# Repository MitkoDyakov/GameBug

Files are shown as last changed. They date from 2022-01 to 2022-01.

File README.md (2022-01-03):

# GameBug
Open Hardware gaming pads for breadboard. 

Each pad features:
* 1 x analog X Y joystics from Adafruit
* 4 x 1.96N OMRON push buttons
* 1 shoulder button
* RGB LED for backlight
* Haptic feedback Maxim Integrated PWM controled vibrator motor driver + motor
* All buttons are debounced using a Texas Instruments schmitt trigger IC to eliminate glitches. 
* 2 x selector switches from Alpine 

It has 2.54 pitch headers for dropping directly into a breadboard. It is powered by 5V or 3.3V.

Great for teaching childer about electronics by bilding their own games.

Suitable for creating your own portable games or HID Joystic devices. 

Can be used to control CNC machines or for DIY RC projects.

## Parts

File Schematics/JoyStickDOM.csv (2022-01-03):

Source: | C:\Users\Dimitar\Documents\PCb Prj\JoySticks\JoyStick\JoyStick.sch
Date: | 1/3/2022 3:54:24 PM
Tool: | Eeschema (5.1.9)-1
Component Count: | 95
Ref | Value | Footprint | Datasheet | Manufacturer | Vendor
C1 | 100nF | Capacitor_SMD:C_0603_1608Metric | ~
C2 | 100nF | Capacitor_SMD:C_0603_1608Metric | ~
C3 | 100nF | Capacitor_SMD:C_0603_1608Metric | ~
C4 | 100nF | Capacitor_SMD:C_0603_1608Metric | ~
C5 | 100nF | Capacitor_SMD:C_0603_1608Metric | ~
C6 | 100nF | Capacitor_SMD:C_0603_1608Metric | ~
C7 | 100nF | Capacitor_SMD:C_0603_1608Metric | ~
C8 | 100nF | Capacitor_SMD:C_0603_1608Metric | ~
C9 | 100nF | Capacitor_SMD:C_0603_1608Metric | ~
C10 | 100nF | Capacitor_SMD:C_0603_1608Metric | ~
C11 | 100nF | Capacitor_SMD:C_0603_1608Metric | ~
C12 | 100nF | Capacitor_SMD:C_0603_1608Metric | ~
C13 | 100nF | Capacitor_SMD:C_0603_1608Metric | ~
C14 | 100nF | Capacitor_SMD:C_0603_1608Metric | ~
D1 | GREEN | LED_SMD:LED_0603_1608Metric | https://github.com/MitkoDyakov/GameBug/blob/main/Datasheets/150060VS75000-1714627.pdf
D2 | GREEN | LED_SMD:LED_0603_1608Metric | https://github.com/MitkoDyakov/GameBug/blob/main/Datasheets/150060VS75000-1714627.pdf
D3 | GREEN | LED_SMD:LED_0603_1608Metric | https://github.com/MitkoDyakov/GameBug/blob/main/Datasheets/150060VS75000-1714627.pdf
D4 | GREEN | LED_SMD:LED_0603_1608Metric | https://github.com/MitkoDyakov/GameBug/blob/main/Datasheets/150060VS75000-1714627.pdf
J1 | Conn_01x06 | Connector_PinHeader_2.54mm:PinHeader_1x06_P2.54mm_Vertical | ~
J2 | Conn_01x07 | Connector_PinHeader_2.54mm:PinHeader_1x07_P2.54mm_Vertical | ~
J3 | Conn_01x02 | Connector_PinHeader_2.54mm:PinHeader_1x02_P2.54mm_Vertical | ~
J4 | Conn_01x06 | Connector_PinHeader_2.54mm:PinHeader_1x06_P2.54mm_Vertical | ~
J5 | Conn_01x02 | Connector_PinHeader_2.54mm:PinHeader_1x02_P2.54mm_Vertical | ~
J6 | Conn_01x05 | Connector_PinHeader_2.54mm:PinHeader_1x05_P2.54mm_Vertical | ~
J7 | Conn_01x02 | Connector_PinHeader_2.54mm:PinHeader_1x02_P2.54mm_Vertical | ~
LED1 | rgb | JoyStick:AELPS1.32 | https://github.com/MitkoDyakov/GameBug/blob/main/Datasheets/KRTB%20AELPS1.32_EN.pdf
LED2 | rgb | JoyStick:AELPS1.32 | https://github.com/MitkoDyakov/GameBug/blob/main/Datasheets/KRTB%20AELPS1.32_EN.pdf
M1 | 306-114 | JoyStick:306-114_motor | https://github.com/MitkoDyakov/GameBug/blob/main/Datasheets/306-114-datasheet-002-d2.2-id5506.pdf
M2 | 306-114 | JoyStick:306-114_motor | https://github.com/MitkoDyakov/GameBug/blob/main/Datasheets/306-114-datasheet-002-d2.2-id5506.pdf
Q1 | PDTC123TU,115 | JoyStick:SOT65P210X110-3N | https://github.com/MitkoDyakov/GameBug/blob/main/Datasheets/PDTC123T_SER-1599447.pdf
Q2 | PDTC123TU,115 | JoyStick:SOT65P210X110-3N | https://github.com/MitkoDyakov/GameBug/blob/main/Datasheets/PDTC123T_SER-1599447.pdf
Q3 | PDTC123TU,115 | JoyStick:SOT65P210X110-3N | https://github.com/MitkoDyakov/GameBug/blob/main/Datasheets/PDTC123T_SER-1599447.pdf
Q4 | PDTC123TU,115 | JoyStick:SOT65P210X110-3N | https://github.com/MitkoDyakov/GameBug/blob/main/Datasheets/PDTC123T_SER-1599447.pdf
Q5 | PDTC123TU,115 | JoyStick:SOT65P210X110-3N | https://github.com/MitkoDyakov/GameBug/blob/main/Datasheets/PDTC123T_SER-1599447.pdf
Q6 | PDTC123TU,115 | JoyStick:SOT65P210X110-3N | https://github.com/MitkoDyakov/GameBug/blob/main/Datasheets/PDTC123T_SER-1599447.pdf
R1 | 100R | Resistor_SMD:R_0603_1608Metric | ~
R2 | 100R | Resistor_SMD:R_0603_1608Metric | ~
R3 | 100R | Resistor_SMD:R_0603_1608Metric | ~
R4 | 4.7K | Resistor_SMD:R_0603_1608Metric | ~
R5 | 1K | Resistor_SMD:R_0603_1608Metric | ~
R6 | 4.7K | Resistor_SMD:R_0603_1608Metric | ~
R7 | 330R | Resistor_SMD:R_0603_1608Metric | ~
R8 | 330R | Resistor_SMD:R_0603_1608Metric | ~
R9 | R_Small | Resistor_SMD:R_0603_1608Metric | ~
R10 | R_Small | Resistor_SMD:R_0603_1608Metric | ~
R11 | 4.7K | Resistor_SMD:R_0603_1608Metric | ~
R12 | 100R | Resistor_SMD:R_0603_1608Metric | ~
R13 | 100R | Resistor_SMD:R_0603_1608Metric | ~
R14 | 100R | Resistor_SMD:R_0603_1608Metric | ~
R15 | 1K | Resistor_SMD:R_0603_1608Metric | ~
R16 | 1K | Resistor_SMD:R_0603_1608Metric | ~
R17 | 1K | Resistor_SMD:R_0603_1608Metric | ~
R18 | 1K | Resistor_SMD:R_0603_1608Metric | ~
R19 | 1K | Resistor_SMD:R_0603_1608Metric | ~
R20 | 1K | Resistor_SMD:R_0603_1608Metric | ~
R21 | 4.7K | Resistor_SMD:R_0603_1608Metric | ~
R22 | 4.7K | Resistor_SMD:R_0603_1608Metric | ~
R23 | 1K | Resistor_SMD:R_0603_1608Metric | ~
R24 | 1K | Resistor_SMD:R_0603_1608Metric | ~
R25 | 1K | Resistor_SMD:R_0603_1608Metric | ~
R26 | 4.7K | Resistor_SMD:R_0603_1608Metric | ~
R27 | 330R | Resistor_SMD:R_0603_1608Metric | ~
R28 | R_Small | Resistor_SMD:R_0603_1608Metric | ~
R29 | R_Small | Resistor_SMD:R_0603_1608Metric | ~
R30 | 330R | Resistor_SMD:R_0603_1608Metric | ~
R31 | 4.7K | Resistor_SMD:R_0603_1608Metric | ~
R32 | 4.7K | Resistor_SMD:R_0603_1608Metric | ~
R33 | 4.7K | Resistor_SMD:R_0603_1608Metric | ~
R34 | 4.7K | Resistor_SMD:R_0603_1608Metric | ~
R35 | 4.7K | Resistor_SMD:R_0603_1608Metric | ~
R36 | 4.7K | Resistor_SMD:R_0603_1608Metric | ~
R37 | 4.7K | Resistor_SMD:R_0603_1608Metric | ~
R38 | 4.7K | Resistor_SMD:R_0603_1608Metric | ~
R39 | 4.7K | Resistor_SMD:R_0603_1608Metric | ~
R40 | 4.7K | Resistor_SMD:R_0603_1608Metric | ~
SW1 | SW_Push | JoyStick:1825968-2 | ~
SW2 | B3AL-1000P | JoyStick:b3al-1000p | https://github.com/MitkoDyakov/GameBug/blob/main/Datasheets/en-b3al-6968.pdf
SW3 | B3AL-1000P | JoyStick:b3al-1000p | https://github.com/MitkoDyakov/GameBug/blob/main/Datasheets/en-b3al-6968.pdf
SW4 | B3AL-1000P | JoyStick:b3al-1000p | https://github.com/MitkoDyakov/GameBug/blob/main/Datasheets/en-b3al-6968.pdf
SW5 | B3AL-1000P | JoyStick:b3al-1000p | https://github.com/MitkoDyakov/GameBug/blob/main/Datasheets/en-b3al-6968.pdf
SW6 | B3AL-1000P | JoyStick:b3al-1000p | https://github.com/MitkoDyakov/GameBug/blob/main/Datasheets/en-b3al-6968.pdf
SW7 | B3AL-1000P | JoyStick:b3al-1000p | https://github.com/MitkoDyakov/GameBug/blob/main/Datasheets/en-b3al-6968.pdf
SW8 | SW_Push | JoyStick:1825968-2 | ~
SW9 | B3AL-1000P | JoyStick:b3al-1000p | https://github.com/MitkoDyakov/GameBug/blob/main/Datasheets/en-b3al-6968.pdf
SW10 | B3AL-1000P | JoyStick:b3al-1000p | https://github.com/MitkoDyakov/GameBug/blob/main/Datasheets/en-b3al-6968.pdf
U1 | SN74HCS14PWR | JoyStick:SOP65P640X120-14N | https://github.com/MitkoDyakov/GameBug/blob/main/Datasheets/sn74hcs14.pdf
U2 | 485-2765 | JoyStick:JOYSTICK_ANALOG_MINITHM | https://github.com/MitkoDyakov/GameBug/blob/main/Datasheets/2765_Web.pdf
U3 | positionSwitch | JoyStick:CL-SB-22A-01 | https://github.com/MitkoDyakov/GameBug/blob/main/Datasheets/cl-sb.pdf
U4 | positionSwitch | JoyStick:CL-SB-22A-01 | https://github.com/MitkoDyakov/GameBug/blob/main/Datasheets/cl-sb.pdf
U5 | MAX1749EUK | JoyStick:21-0057F | https://github.com/MitkoDyakov/GameBug/blob/main/Datasheets/MAX1749-1515329.pdf
U6 | 485-2765 | JoyStick:JOYSTICK_ANALOG_MINITHM | https://github.com/MitkoDyakov/GameBug/blob/main/Datasheets/2765_Web.pdf
U7 | SN74HCS14PWR | JoyStick:SOP65P640X120-14N | https://github.com/MitkoDyakov/GameBug/blob/main/Datasheets/sn74hcs14.pdf
U8 | CL-SB-22A-01T | JoyStick:CL-SB-22A-01 | https://github.com/MitkoDyakov/GameBug/blob/main/Datasheets/cl-sb.pdf
U9 | MAX1749EUK | JoyStick:21-0057F | https://github.com/MitkoDyakov/GameBug/blob/main/Datasheets/MAX1749-1515329.pdf
U10 | CL-SB-22A-01T | JoyStick:CL-SB-22A-01 | https://github.com/MitkoDyakov/GameBug/blob/main/Datasheets/cl-sb.pdf

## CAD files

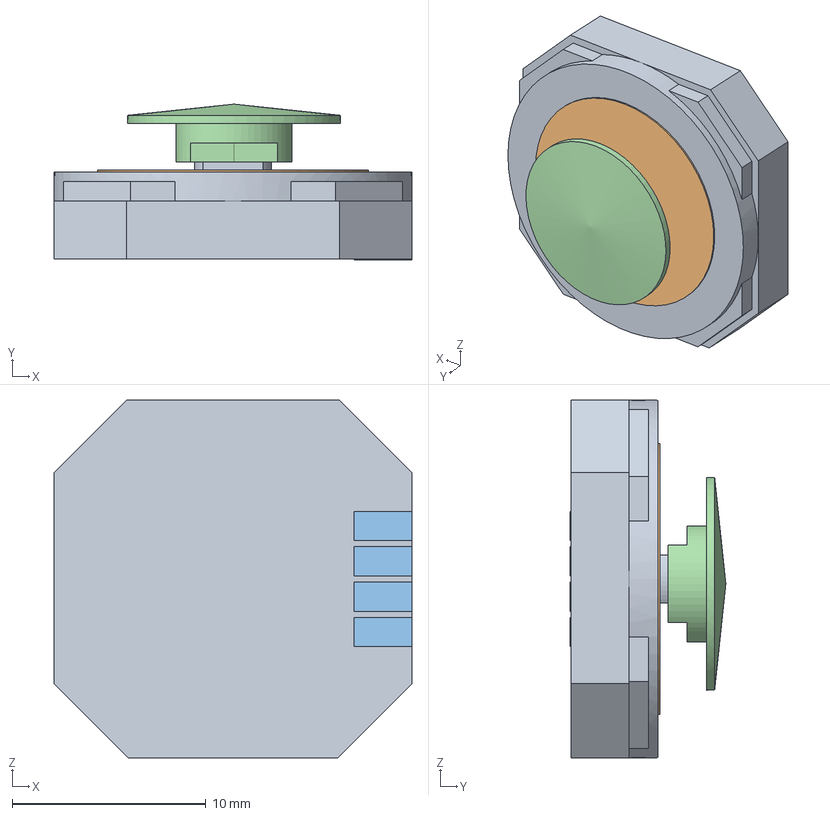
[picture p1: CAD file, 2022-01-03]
CAD models/components/joyStick.step
18.5 x 8.05 x 18.5 mm

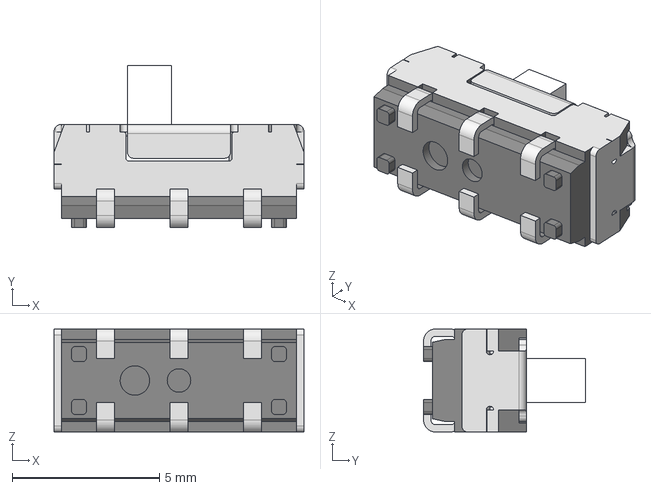
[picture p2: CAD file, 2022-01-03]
CAD models/components/CL-SB-22A-01.stp
8.50 x 5.50 x 3.50 mm
_22A-01_c
_2Top setting_s

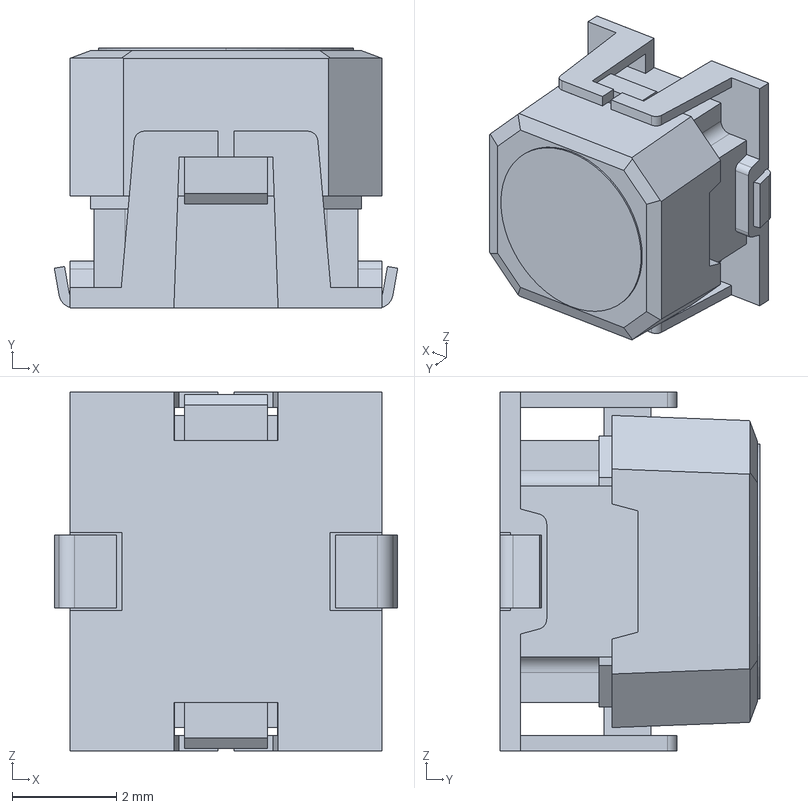
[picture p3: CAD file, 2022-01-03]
CAD models/components/omron_btn.stp
6.60 x 5.00 x 6.90 mm

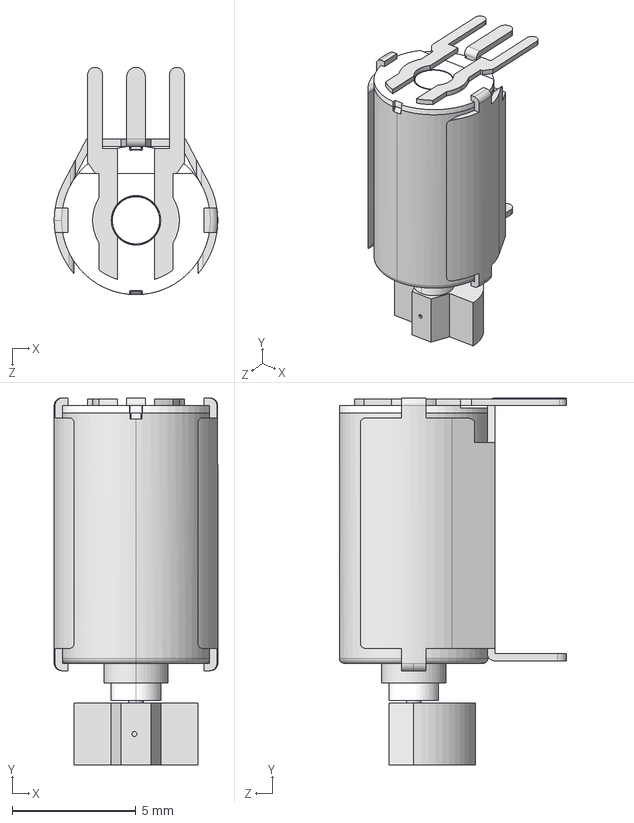
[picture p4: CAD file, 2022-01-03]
CAD models/components/motor.STEP
6.60 x 14.8 x 9.17 mm
m_main___
M_cover___
m_main cover___
weight___

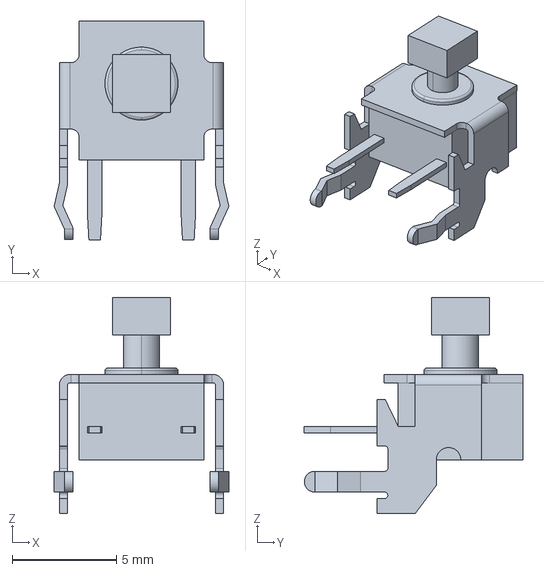
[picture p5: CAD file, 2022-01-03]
CAD models/components/c-1825968-2-b-3d.stp
8.40 x 10.5 x 10.4 mm

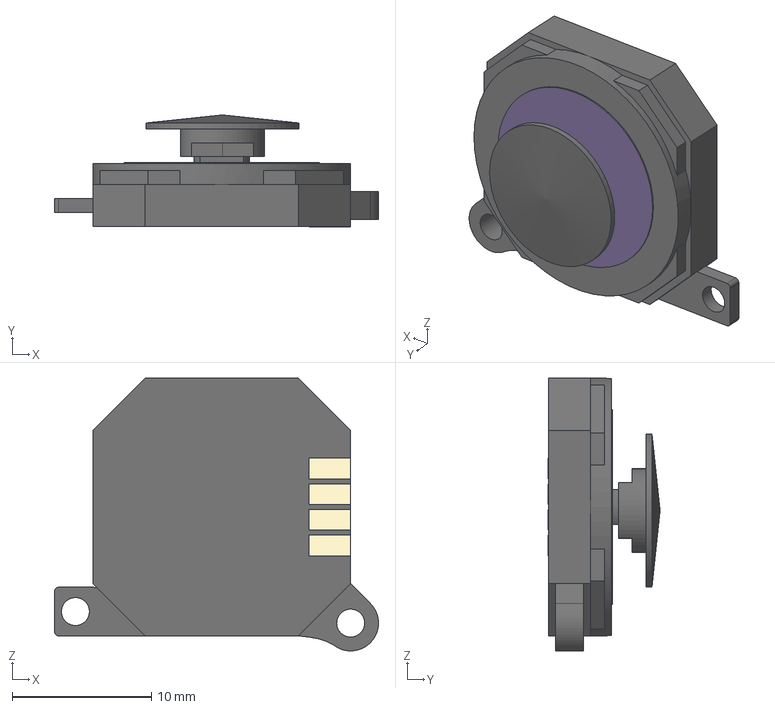
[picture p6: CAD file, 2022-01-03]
CAD models/components/PspJoystick v5.step
23.2 x 8.05 x 19.6 mm

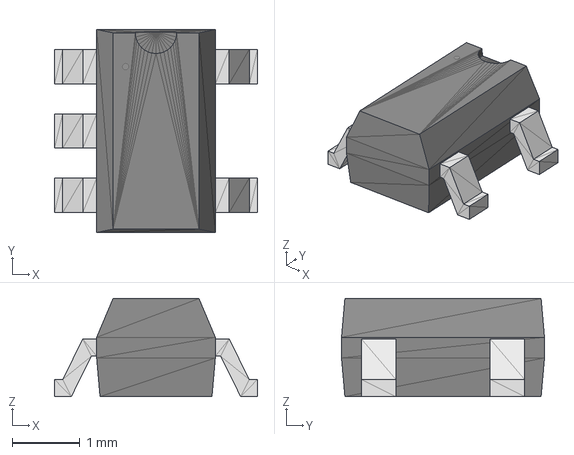
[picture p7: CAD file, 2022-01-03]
CAD models/components/MAX1749EUK+.STEP
3.00 x 3.00 x 1.45 mm

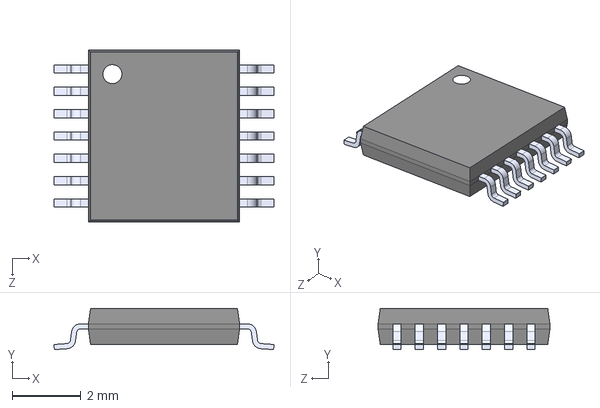
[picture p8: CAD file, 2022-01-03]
CAD models/components/SOP65P640X120-14N.step
6.40 x 1.20 x 5.00 mm

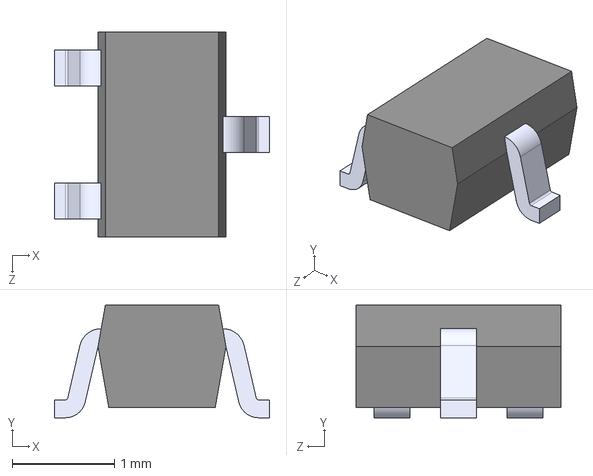
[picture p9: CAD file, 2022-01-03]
CAD models/components/SOT65P210X110-3N.step
2.10 x 1.10 x 2.00 mm

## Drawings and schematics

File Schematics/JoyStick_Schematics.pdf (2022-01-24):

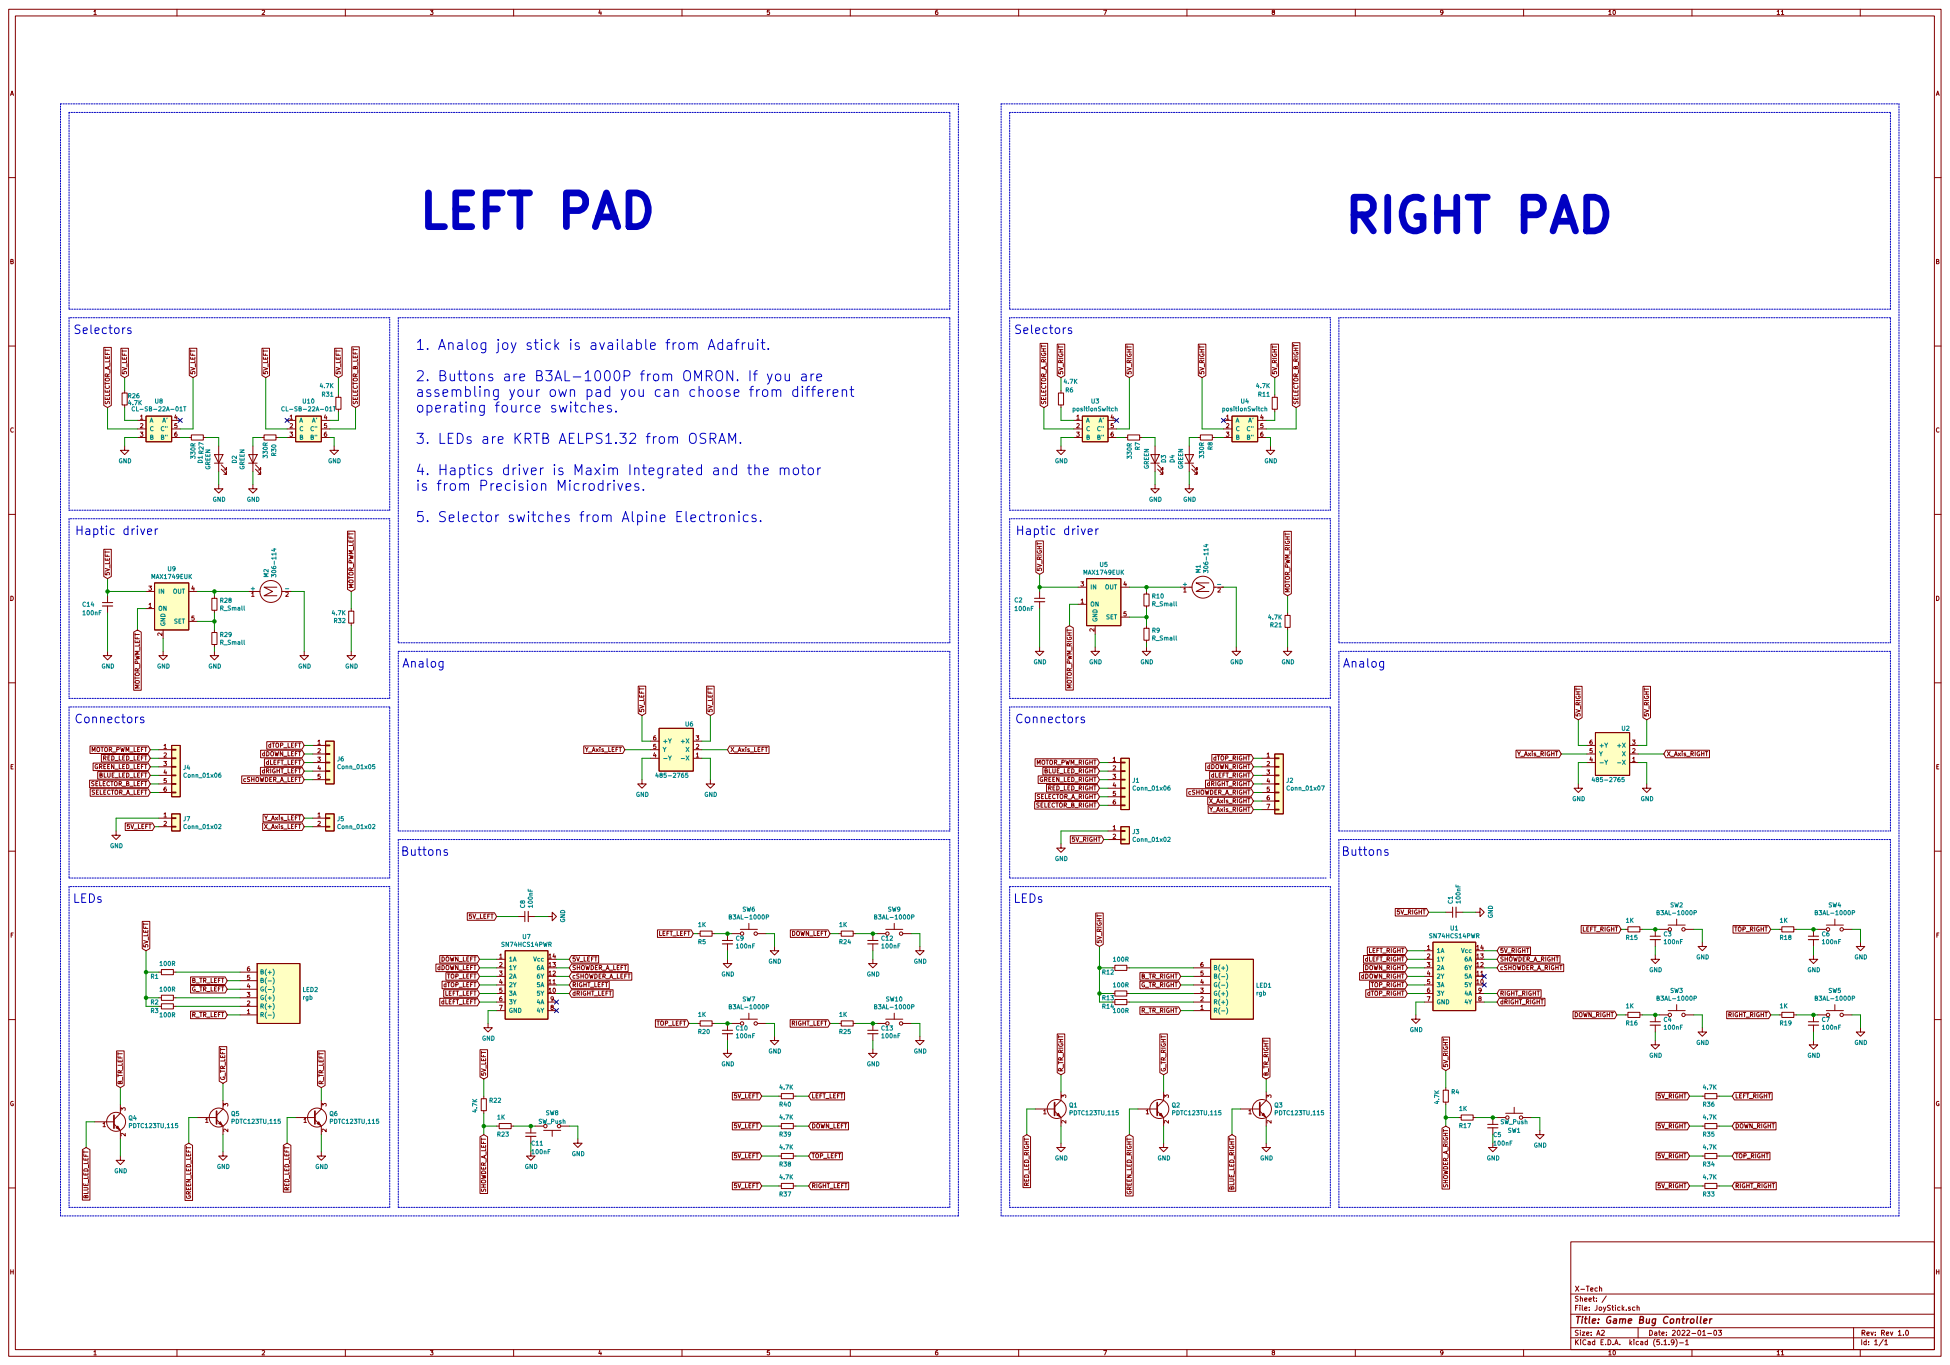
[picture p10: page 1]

1. Analog joy stick is available from Adafruit.
2. Buttons are B3AL-1000P from OMRON. If you are
assembling your own pad you can choose from different
operating fource switches.
3. LEDs are KRTB AELPS1.32 from OSRAM.
4. Haptics driver is Maxim Integrated and the motor
is from Precision Microdrives.
5. Selector switches from Alpine Electronics.

File: JoyStick.sch Sheet: / X-Tech 330R R30

Id: 1/1 Title: Game Bug Controller

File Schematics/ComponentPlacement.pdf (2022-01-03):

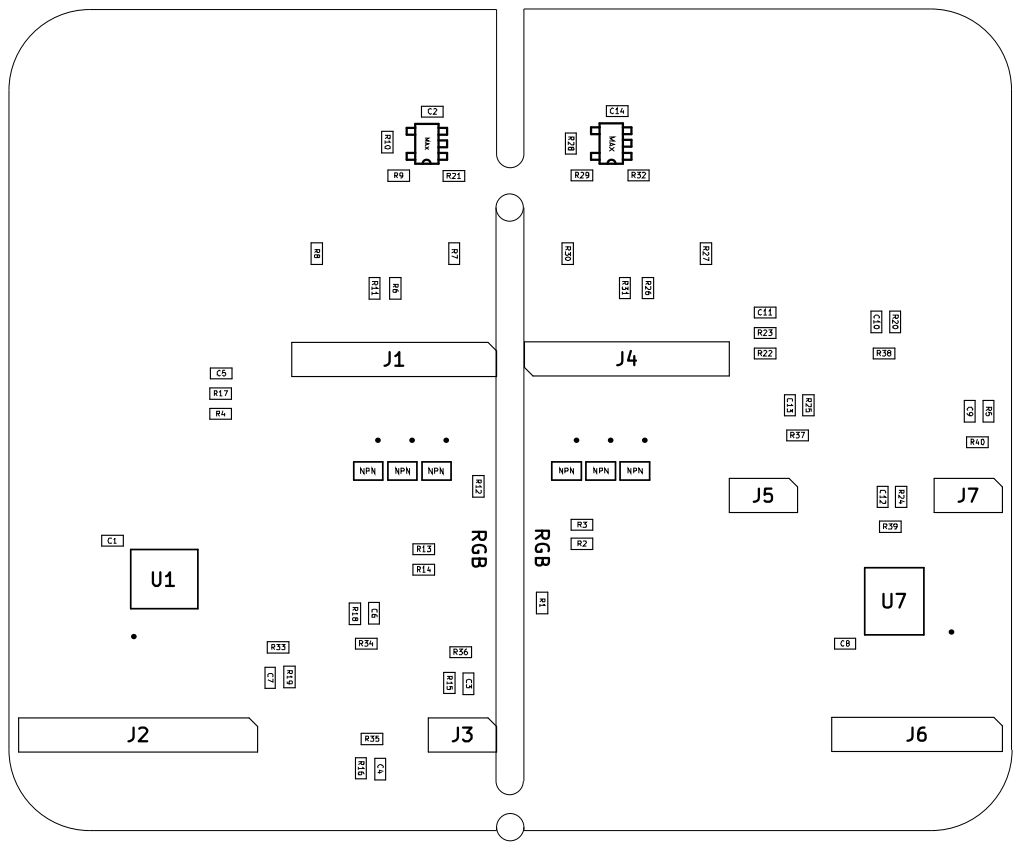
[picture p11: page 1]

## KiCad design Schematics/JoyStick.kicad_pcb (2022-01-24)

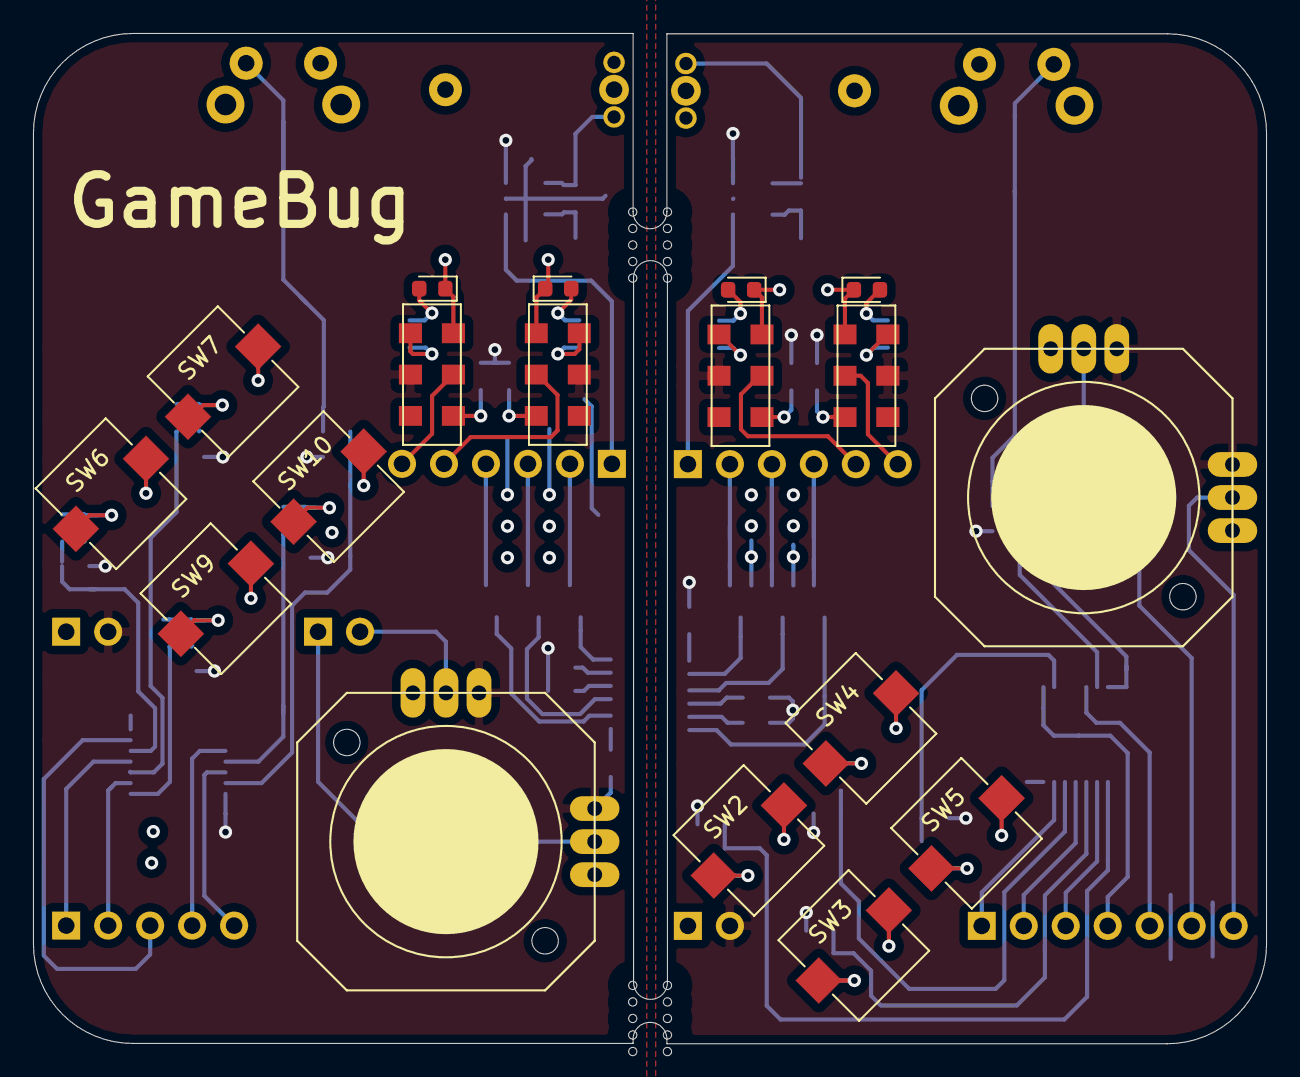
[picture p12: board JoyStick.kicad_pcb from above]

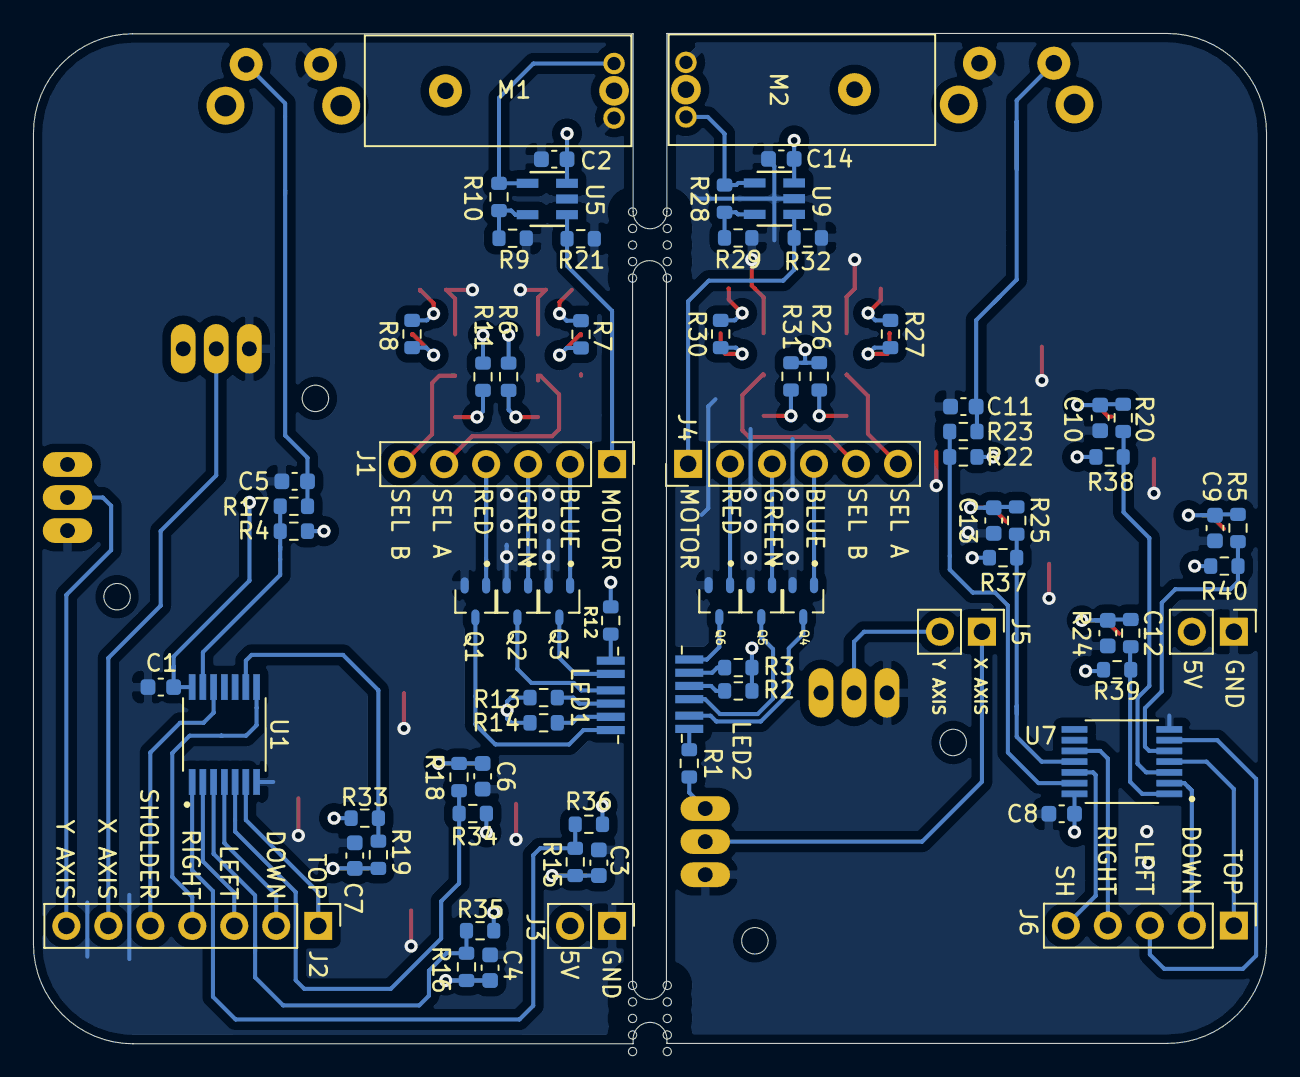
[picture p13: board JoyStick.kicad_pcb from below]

Board: 4 copper layers, 74.6 x 61.1 mm, 95 parts (75 on the bottom side), 77 nets.

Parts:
C1, C2, C3, C4, C5, C6, C7, C8, C9, C10, C11, C12, C13, C14: 100nF; C_0603_1608Metric
D1, D2, D3, D4: LED; LED_0603_1608Metric
J1, J4: Conn_01x06; PinHeader_1x06_P2.54mm_Vertical
J2: Conn_01x07; PinHeader_1x07_P2.54mm_Vertical
J3, J5, J7: Conn_01x02; PinHeader_1x02_P2.54mm_Vertical
J6: Conn_01x05; PinHeader_1x05_P2.54mm_Vertical
LED1, LED2: RGB; AELPS1.32
M1, M2: Motor_DC; 306-114_motor
Q1, Q2, Q3, Q4, Q5, Q6: NPN; SOT65P210X110-3N
R1, R2, R3, R4, R5, R6, R7, R8, R9, R10, R11, R12, R13, R14, R15, R16, R17, R18, R19, R20, R21, R22, R23, R24, R25, R26, R27, R28, R29, R30, R31, R32, R33, R34, R35, R36, R37, R38, R39, R40: R_Small; R_0603_1608Metric
SW1, SW8: SW_Push; 1825968-2
SW2, SW3, SW4, SW5, SW6, SW7, SW9, SW10: SW_Push; b3al-1000p
U1: U1; SOP65P640X120-14N
U2, U6: AnalogJoyStick; JOYSTICK_ANALOG_MINITHM
U3, U4, U8, U10: positionSwitch; CL-SB-22A-01
U5, U9: MAX; 21-0057F
U7: U7; SOP65P640X120-14N

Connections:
5V: C1.1, C2.1, J3.2, R4.2, R6.2, R11.2, R12.2, R13.2, R14.2, R33.1, R34.1, R35.1, R36.1, U1.14, U2.3, U2.6, U3.5, U4.2, U5.3
5V_2: C8.1, C14.1, J7.2, R1.2, R2.2, R3.2, R22.2, R26.2, R31.2, R37.1, R38.1, R39.1, R40.1, U6.3, U6.6, U7.14, U8.5, U9.3, U10.2
BLUE_LED: J1.2, Q3.1
BLUE_LED_2: J4.4, Q4.1
B_TR: LED1.5, Q3.3
B_TR_2: LED2.5, Q4.3
DOWN: R16.1, R35.2, U1.3
DOWN_2: R24.1, R39.2, U7.1
GND: C1.2, C2.2, C3.2, C4.2, C5.2, C6.2, C7.2, C8.2, C9.2, C10.2, C11.2, C12.2, C13.2, C14.2, D1.1, D2.1, D3.1, D4.1, J3.1, J7.1, M1.2, M2.2, Q1.2, Q2.2, Q3.2, Q4.2, Q5.2, Q6.2, R9.2, R21.1, R29.2, R32.1, SW1.2, SW2.2, SW3.2, SW4.2, SW5.2, SW6.2, SW7.2, SW8.1, SW9.2, SW10.2, U1.7, U2.1, U2.4, U3.3, U4.6, U5.2, U6.1, U6.4, U7.7, U8.3, U9.2, U10.6
GREEN_LED: J1.3, Q2.1
GREEN_LED_2: J4.3, Q5.1
G_TR: LED1.4, Q2.3
G_TR_2: LED2.4, Q5.3
LEFT: R15.1, R36.2, U1.1
LEFT_2: R5.1, R40.2, U7.5
MOTOR_PWM: J1.1, R21.2, U5.1
MOTOR_PWM_2: J4.1, R32.2, U9.1
unnamed: C3.1, R15.2, SW2.1
unnamed: C4.1, R16.2, SW3.1
unnamed: C5.1, R17.2, SW1.1
unnamed: C6.1, R18.2, SW4.1
unnamed: C7.1, R19.2, SW5.1
unnamed: C9.1, R5.2, SW6.1
unnamed: C10.1, R20.2, SW7.1
unnamed: C11.1, R23.2, SW8.2
unnamed: C12.1, R24.2, SW9.1
unnamed: C13.1, R25.2, SW10.1
unnamed: D1.2, R27.1
unnamed: D2.2, R30.2
unnamed: D3.2, R7.1
unnamed: D4.2, R8.2
unnamed: LED1.2, R14.1
unnamed: LED1.3, R13.1
unnamed: LED1.6, R12.1
unnamed: LED2.2, R3.1
unnamed: LED2.3, R2.1
unnamed: LED2.6, R1.1
unnamed: M1.1, R10.1, U5.4
unnamed: M2.1, R28.1, U9.4
unnamed: R6.1, U3.1
unnamed: R7.2, U3.6
unnamed: R8.1, U4.3
unnamed: R9.1, R10.2, U5.5
unnamed: R11.1, U4.4
unnamed: R26.1, U8.1
unnamed: R27.2, U8.6
unnamed: R28.2, R29.1, U9.5
unnamed: R30.1, U10.3
unnamed: R31.1, U10.4
RED_LED: J1.4, Q1.1
RED_LED_2: J4.2, Q6.1
RIGHT: R19.1, R33.2, U1.9
RIGHT_2: R25.1, R37.2, U7.11
R_TR: LED1.1, Q1.3
R_TR_2: LED2.1, Q6.3
SELECTOR_A: J1.5, U3.2
SELECTOR_A_2: J4.6, U8.2
SELECTOR_B: J1.6, U4.5
SELECTOR_B_2: J4.5, U10.5
SHOWDER_A: R4.1, R17.1, U1.13
SHOWDER_A_2: R22.1, R23.1, U7.13
TOP: R18.1, R34.2, U1.5
TOP_2: R20.1, R38.2, U7.3
X_Axis: J2.6, U2.2
X_Axis_2: J5.2, U6.2
Y_Axis: J2.7, U2.5
Y_Axis_2: J5.1, U6.5
cSHOWDER_A: J2.5, U1.12
cSHOWDER_A_2: J6.5, U7.12
dDOWN: J2.2, U1.4
dDOWN_2: J6.2, U7.2
dLEFT: J2.3, U1.2
dLEFT_2: J6.3, U7.6
dRIGHT: J2.4, U1.8
dRIGHT_2: J6.4, U7.10
dTOP: J2.1, U1.6
dTOP_2: J6.1, U7.4

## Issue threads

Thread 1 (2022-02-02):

Създадох този issue, защото не знаех как да се свържа с теб

NikolaTotev, 2022-02-02:
Здравей!
Знам че не е най-подходящия начин за комуникация, но само този канал намерих.
Твоя gamepad го видях на сайта на Hackster.io и се зарадвах като видях, че човека е българин!

Аз също си падам по електроника/роботика, и от дълго време търся други хора, които имат същите интереси.
Много бих се радвал ако може да си разменим някакви координати. За мен всичко работи, дискорд, фб, имейл и тн.

Поздрави,
Никола

MitkoDyakov, 2022-02-02:
Здравей Никола!

Разбира се ще се радвам да разменим контакти! Може да ми пратиш един мейл на dimitar ат xtech.bg

Поздрави,
Митко

Closed 2022-02-02.

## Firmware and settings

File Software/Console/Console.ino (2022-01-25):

#include <Arduino.h>
#include <XInput.h>

//LEFT PAD
#define LEFT_JOYSTICK_X_AXIS     (A3)
#define LEFT_JOYSTICK_Y_AXIS     (A2)

#define LEFT_VIBRATOR_MOTOR      (10)
#define LEFT_LIGHT_RED           (3)
#define LEFT_LIGHT_GREEN         (5)
#define LEFT_LIGHT_BLUE          (6)

//RIGHT PAD
#define RIGHT_JOYSTICK_X_AXIS    (A0)
#define RIGHT_JOYSTICK_Y_AXIS    (A1)
#define RIGHT_SHOULDER_BTN       (14)
#define RIGHT_BTN_UP             (9)
#define RIGHT_BTN_LEFT           (7)
#define RIGHT_BTN_RIGHT          (16)
#define RIGHT_BTN_DOWN           (8)

const int ADC_Max = 1023;  // 10 bit

void setup() 
{                
  pinMode(LEFT_JOYSTICK_X_AXIS, INPUT);
  pinMode(LEFT_JOYSTICK_Y_AXIS, INPUT);
  pinMode(LEFT_VIBRATOR_MOTOR, OUTPUT);
  pinMode(LEFT_LIGHT_RED, OUTPUT);
  pinMode(LEFT_LIGHT_GREEN, OUTPUT);
  pinMode(LEFT_LIGHT_BLUE, OUTPUT);

  pinMode(RIGHT_JOYSTICK_X_AXIS, INPUT);
  pinMode(RIGHT_JOYSTICK_Y_AXIS, INPUT);
  pinMode(RIGHT_SHOULDER_BTN, INPUT);
  pinMode(RIGHT_BTN_LEFT, INPUT);
  pinMode(RIGHT_BTN_RIGHT, INPUT);
  pinMode(RIGHT_BTN_DOWN, INPUT);

  XInput.setJoystickRange(0, ADC_Max);  // Set joystick range to the ADC
  XInput.setAutoSend(false);  // Wait for all controls before sending

  XInput.begin();
}

void loop() 
{
  boolean tmpVal = 0;
  int tmpJoyX = 0;
  int tmpJoyY = 0;
  
  tmpVal = digitalRead(RIGHT_BTN_DOWN);
  XInput.setButton(BUTTON_A, tmpVal);

  tmpVal = digitalRead(RIGHT_BTN_RIGHT);
  XInput.setButton(BUTTON_B, tmpVal);

  tmpVal = digitalRead(RIGHT_BTN_LEFT);
  XInput.setButton(BUTTON_X, tmpVal);
  
  tmpVal = digitalRead(RIGHT_BTN_UP);
  XInput.setButton(BUTTON_Y, tmpVal);

  tmpVal = digitalRead(RIGHT_SHOULDER_BTN);
  XInput.setButton(BUTTON_RB, tmpVal);
  
  tmpJoyX = analogRead(LEFT_JOYSTICK_X_AXIS);
  tmpJoyY = analogRead(LEFT_JOYSTICK_Y_AXIS);
  XInput.setJoystickX(JOY_LEFT, tmpJoyX, true);
  XInput.setJoystickY(JOY_LEFT, tmpJoyY, true);

  tmpJoyX = analogRead(RIGHT_JOYSTICK_X_AXIS);
  tmpJoyY = analogRead(RIGHT_JOYSTICK_Y_AXIS);
  XInput.setJoystickX(JOY_RIGHT, tmpJoyX, true);
  XInput.setJoystickY(JOY_RIGHT, tmpJoyY, true);

  // Send control data to the computer
  XInput.send();
}

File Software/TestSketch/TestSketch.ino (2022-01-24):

#include <Arduino.h>

// 1. Connect the GameBug pin to Arduino IO
// 2. Uncooment the control you are using
// 3. Write the pin number in the brackets 

//LEFT PAD INPUTS
//#define LEFT_JOYSTICK_X_AXIS     ()
//#define LEFT_JOYSTICK_Y_AXIS     ()
//#define LEFT_SHOULDER_BTN        ()
//#define LEFT_BTN_UP              ()
//#define LEFT_BTN_LEFT            ()
//#define LEFT_BTN_RIGHT           ()
//#define LEFT_BTN_DOWN            ()
//#define LEFT_SELECTOR_A          ()
//#define LEFT_SELECTOR_B          ()
//LEFT PAD OUTPUTS
//#define LEFT_VIBRATOR_MOTOR      ()
//#define LEFT_LIGHT_RED           ()
//#define LEFT_LIGHT_GREEN         ()
//#define LEFT_LIGHT_BLUE          ()

//RIGHT PAD INPUTS
//#define RIGHT_JOYSTICK_X_AXIS    ()
//#define RIGHT_JOYSTICK_Y_AXIS    ()
//#define RIGHT_SHOULDER_BTN       ()
//#define RIGHT_BTN_UP             ()
//#define RIGHT_BTN_LEFT           ()
//#define RIGHT_BTN_RIGHT          ()
//#define RIGHT_BTN_DOWN           ()
//#define RIGHT_SELECTOR_A         ()
//#define RIGHT_SELECTOR_B         ()
//RIGHT PAD OUTPUTS
//#define RIGHT_VIBRATOR_MOTOR     ()
//#define RIGHT_LIGHT_RED          ()
//#define RIGHT_LIGHT_GREEN        ()
//#define RIGHT_LIGHT_BLUE         ()

void setup() 
{
                 
#ifdef LEFT_JOYSTICK_X_AXIS   
  pinMode(LEFT_JOYSTICK_X_AXIS, INPUT);
#endif

#ifdef LEFT_JOYSTICK_Y_AXIS   
  pinMode(LEFT_JOYSTICK_Y_AXIS, INPUT);
#endif          
   
#ifdef LEFT_SHOULDER_BTN      
  pinMode(LEFT_SHOULDER_BTN, INPUT);
#endif

#ifdef LEFT_BTN_UP          
  pinMode(LEFT_BTN_UP, INPUT);
#endif
  
#ifdef LEFT_BTN_LEFT      
  pinMode(LEFT_BTN_LEFT, INPUT);
#endif
    
#ifdef LEFT_BTN_RIGHT     
  pinMode(LEFT_BTN_RIGHT, INPUT);
#endif
    
#ifdef LEFT_BTN_DOWN 
  pinMode(LEFT_BTN_DOWN, INPUT);
#endif
         
#ifdef LEFT_SELECTOR_A 
  pinMode(LEFT_SELECTOR_A, INPUT);
#endif
       
#ifdef LEFT_SELECTOR_B 
  pinMode(LEFT_SELECTOR_B, INPUT);
#endif
            
#ifdef LEFT_VIBRATOR_MOTOR    
  pinMode(LEFT_VIBRATOR_MOTOR, OUTPUT);
#endif

#ifdef LEFT_LIGHT_RED  
  pinMode(LEFT_LIGHT_RED, OUTPUT);
#endif
       
#ifdef LEFT_LIGHT_GREEN
  pinMode(LEFT_LIGHT_GREEN, OUTPUT);
#endif
       
#ifdef LEFT_LIGHT_BLUE   
  pinMode(LEFT_LIGHT_BLUE, OUTPUT);
#endif     
                  
#ifdef RIGHT_JOYSTICK_X_AXIS  
  pinMode(RIGHT_JOYSTICK_X_AXIS, INPUT);
#endif

#ifdef RIGHT_JOYSTICK_Y_AXIS  
  pinMode(RIGHT_JOYSTICK_Y_AXIS, INPUT);
#endif
                        
#ifdef RIGHT_SHOULDER_BTN   
  pinMode(RIGHT_SHOULDER_BTN, INPUT);
#endif
  
#ifdef RIGHT_BTN_UP 
  pinMode(RIGHT_BTN_UP, INPUT);
#endif
          
#ifdef RIGHT_BTN_LEFT   
  pinMode(RIGHT_BTN_LEFT, INPUT);
#endif
      
#ifdef RIGHT_BTN_RIGHT  
  pinMode(RIGHT_BTN_RIGHT, INPUT);
#endif
      
#ifdef RIGHT_BTN_DOWN 
  pinMode(RIGHT_BTN_DOWN, INPUT);
#endif
        
#ifdef RIGHT_SELECTOR_A   
  pinMode(RIGHT_SELECTOR_A, INPUT);
#endif
    
#ifdef RIGHT_SELECTOR_B   
  pinMode(RIGHT_SELECTOR_B, INPUT);
#endif    
                        
#ifdef RIGHT_VIBRATOR_MOTOR  
  pinMode(RIGHT_VIBRATOR_MOTOR, OUTPUT);
#endif
 
#ifdef RIGHT_LIGHT_RED    
  pinMode(RIGHT_LIGHT_RED, OUTPUT);
#endif
    
#ifdef RIGHT_LIGHT_GREEN 
  pinMode(RIGHT_LIGHT_GREEN, OUTPUT);
#endif
   
#ifdef RIGHT_LIGHT_BLUE  
  pinMode(RIGHT_LIGHT_BLUE, OUTPUT);
#endif

  Serial.begin(9600);
}

void loop() {
  int axis;
  uint8_t tmp = 0;

  Serial.println("\tLeft\t\tRight");
  Serial.print("X\t");
  
#ifdef LEFT_JOYSTICK_X_AXIS
  axis = analogRead(LEFT_JOYSTICK_X_AXIS);
  Serial.print(axis);
#else 
  Serial.print("NA");
#endif
  Serial.print("\t\t");
#ifdef RIGHT_JOYSTICK_X_AXIS
  axis = analogRead(RIGHT_JOYSTICK_X_AXIS);
  Serial.println(axis);
#else 
  Serial.println("NA");
#endif

Serial.print("Y\t");  
#ifdef LEFT_JOYSTICK_Y_AXIS
  axis = analogRead(LEFT_JOYSTICK_Y_AXIS);
  Serial.print(axis);
#else 
  Serial.print("NA");
#endif
  Serial.print("\t\t");
#ifdef RIGHT_JOYSTICK_Y_AXIS
  axis = analogRead(RIGHT_JOYSTICK_Y_AXIS);
  Serial.println(axis);
#else 
  Serial.println("NA");
#endif

  
  Serial.print("Sh\t");
#ifdef LEFT_SHOULDER_BTN
  tmp = digitalRead(LEFT_SHOULDER_BTN);
  Serial.print(tmp);
#else
  Serial.print("NA");
#endif
  Serial.print("\t\t");
#ifdef RIGHT_SHOULDER_BTN
  tmp = digitalRead(RIGHT_SHOULDER_BTN);
  Serial.println(tmp);
#else
  Serial.println("NA");
#endif
  
  Serial.print("L\t");
#ifdef LEFT_BTN_LEFT
  tmp = digitalRead(LEFT_BTN_LEFT);
  Serial.print(tmp);
#else
  Serial.print("NA");
#endif
  Serial.print("\t\t");
#ifdef RIGHT_BTN_LEFT
  tmp = digitalRead(RIGHT_BTN_LEFT);
  Serial.println(tmp);
#else
  Serial.println("NA");
#endif
  
  Serial.print("R\t");
#ifdef LEFT_BTN_RIGHT
  tmp = digitalRead(LEFT_BTN_RIGHT);
  Serial.print(tmp);
#else
  Serial.print("NA");
#endif
  Serial.print("\t\t");
#ifdef RIGHT_BTN_RIGHT
  tmp = digitalRead(RIGHT_BTN_RIGHT);
  Serial.println(tmp);
#else
  Serial.println("NA");
#endif
  
  Serial.print("U\t");
#ifdef LEFT_BTN_UP
  tmp = digitalRead(LEFT_BTN_UP);
  Serial.print(tmp);
#else
  Serial.print("NA");
#endif
  Serial.print("\t\t");
#ifdef RIGHT_BTN_UP
  tmp = digitalRead(RIGHT_BTN_UP);
  Serial.println(tmp);
#else
  Serial.println("NA");
#endif
  
  Serial.print("D\t");
#ifdef LEFT_BTN_DOWN
  tmp = digitalRead(LEFT_BTN_DOWN);
  Serial.print(tmp);
#else
  Serial.print("NA");
#endif
  Serial.print("\t\t");
#ifdef RIGHT_BTN_DOWN
  tmp = digitalRead(RIGHT_BTN_DOWN);
  Serial.println(tmp);
#else
  Serial.println("NA");
#endif
  
  Serial.print("SA\t");
#ifdef LEFT_SELECTOR_A
  tmp = digitalRead(LEFT_SELECTOR_A);
  Serial.print(tmp);
#else
  Serial.print("NA");
#endif
  Serial.print("\t\t");
#ifdef RIGHT_SELECTOR_A
  tmp = digitalRead(RIGHT_SELECTOR_A);
  Serial.println(tmp);
#else
  Serial.println("NA");
#endif
  
  Serial.print("SB\t");
#ifdef LEFT_SELECTOR_B
  tmp = digitalRead(LEFT_SELECTOR_B);
  Serial.print(tmp);
#else
  Serial.print("NA");
#endif
  Serial.print("\t\t");
#ifdef RIGHT_SELECTOR_B
  tmp = digitalRead(RIGHT_SELECTOR_B);
  Serial.println(tmp);
#else
  Serial.println("NA");
#endif

  Serial.println();
  Serial.println("send L for LED demo or M for motor demo");
  Serial.println("-----------------------------------------------------------------");
  Serial.println();


  uint8_t i = 0;
  int incomingByte = 0;

  if (Serial.available() > 0) 
  {
    incomingByte = Serial.read();
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

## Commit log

2022-01-03 cads
    cad models
    [CL-SB-22A-01.stp, MAX1749EUK+.STEP, PspJoystick v5.step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]
2022-01-03 Update JoyStick.step
    Added shoulder buttons
2022-01-03 Man files
    PCB bom and component placement
    [JoyStick.kicad_pcb, JoyStickDOM.csv]
2022-01-24 fix for motor pull down
2022-01-24 fix for motor pull down
    fix for
    [JoyStick.kicad_pcb]

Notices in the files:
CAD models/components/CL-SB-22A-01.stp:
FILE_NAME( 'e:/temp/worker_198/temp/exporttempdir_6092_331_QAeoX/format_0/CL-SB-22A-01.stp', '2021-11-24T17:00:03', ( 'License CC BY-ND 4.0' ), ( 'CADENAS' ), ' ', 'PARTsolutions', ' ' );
